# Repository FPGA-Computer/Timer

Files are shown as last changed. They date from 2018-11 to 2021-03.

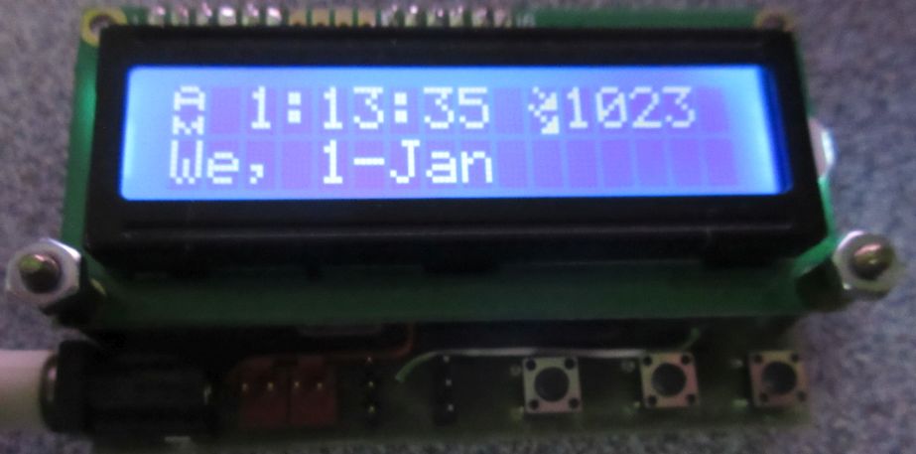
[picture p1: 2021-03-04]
V2/hardware/PCB + LCD.jpg

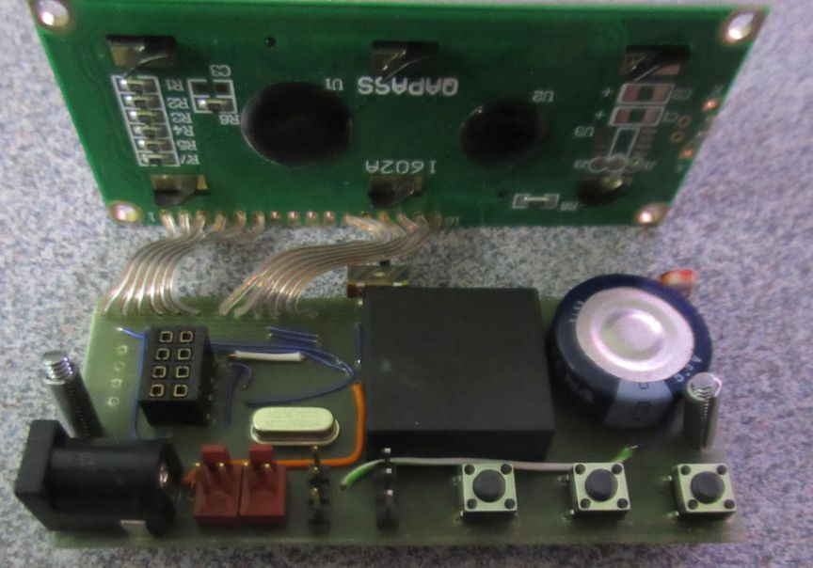
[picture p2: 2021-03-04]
V2/hardware/PCB top.jpg

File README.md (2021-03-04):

STM8S003 Timer

This is a timer for watering plant and supplyment light in the winter with LED.
There is a simple menu system (UI.C,UI.H) for setting preferences that may be of interest.

Schematic/layout: Eagle CAD. Firmware compiled using "Free" Cosmic C for the STM8 series.

Project page:

https://hw-by-design.blogspot.com/2018/10/stm8-timer.html

Licensing:

Firmware: Unless otherwise stated are in GPL3.0. stm8s.h is licensed under "MCD-ST Liberty SW License Agreement V2"

Schematic: Creative Commons 4.0 Attribution 4.0 International

PCB & Layout: Creative Commons 4.0 Attribution 4.0 International

See https://creativecommons.org/licenses/by/4.0/

Change log
- back port from LED clock project: NCO for better trimming, Daylight Saving Time, Date and leap year

- Mar 18 2020: Servo support + fixing alarm remainder time after time adjustment

- Mar 4 2021: V2 hardware/firmware release.  V1 will no longer be maintained

Hardware changes:

* Supercap backup power, switcher module

* Different connector for LED/sensor + Servo connector

* LCD, buttons I/O changes. LCD backlight on/off control by ambient light

* I2C connector

* expansion connector for nRF24 (no firmware support)

See https://hw-by-design.blogspot.com/2020/03/stm8-timer-servo-controlled-water-valve.html

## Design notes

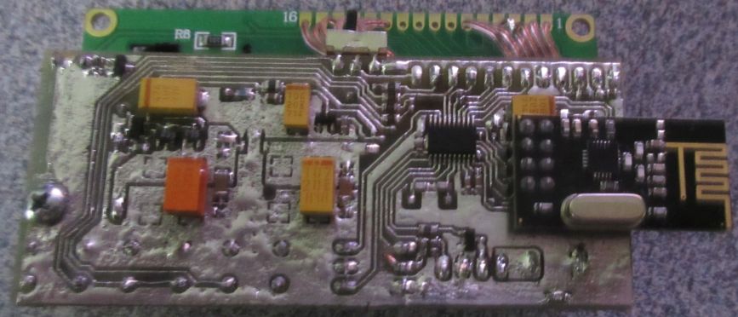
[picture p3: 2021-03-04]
V2/hardware/PCB with nRF24 module.jpg

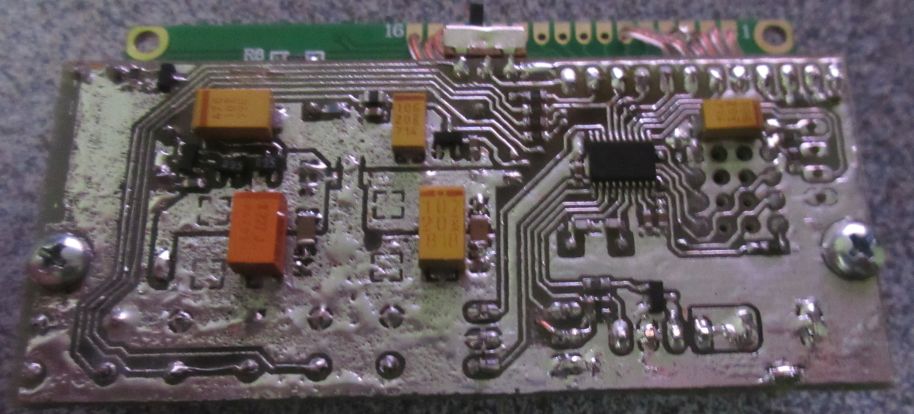
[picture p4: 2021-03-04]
V2/hardware/PCB bot.jpg

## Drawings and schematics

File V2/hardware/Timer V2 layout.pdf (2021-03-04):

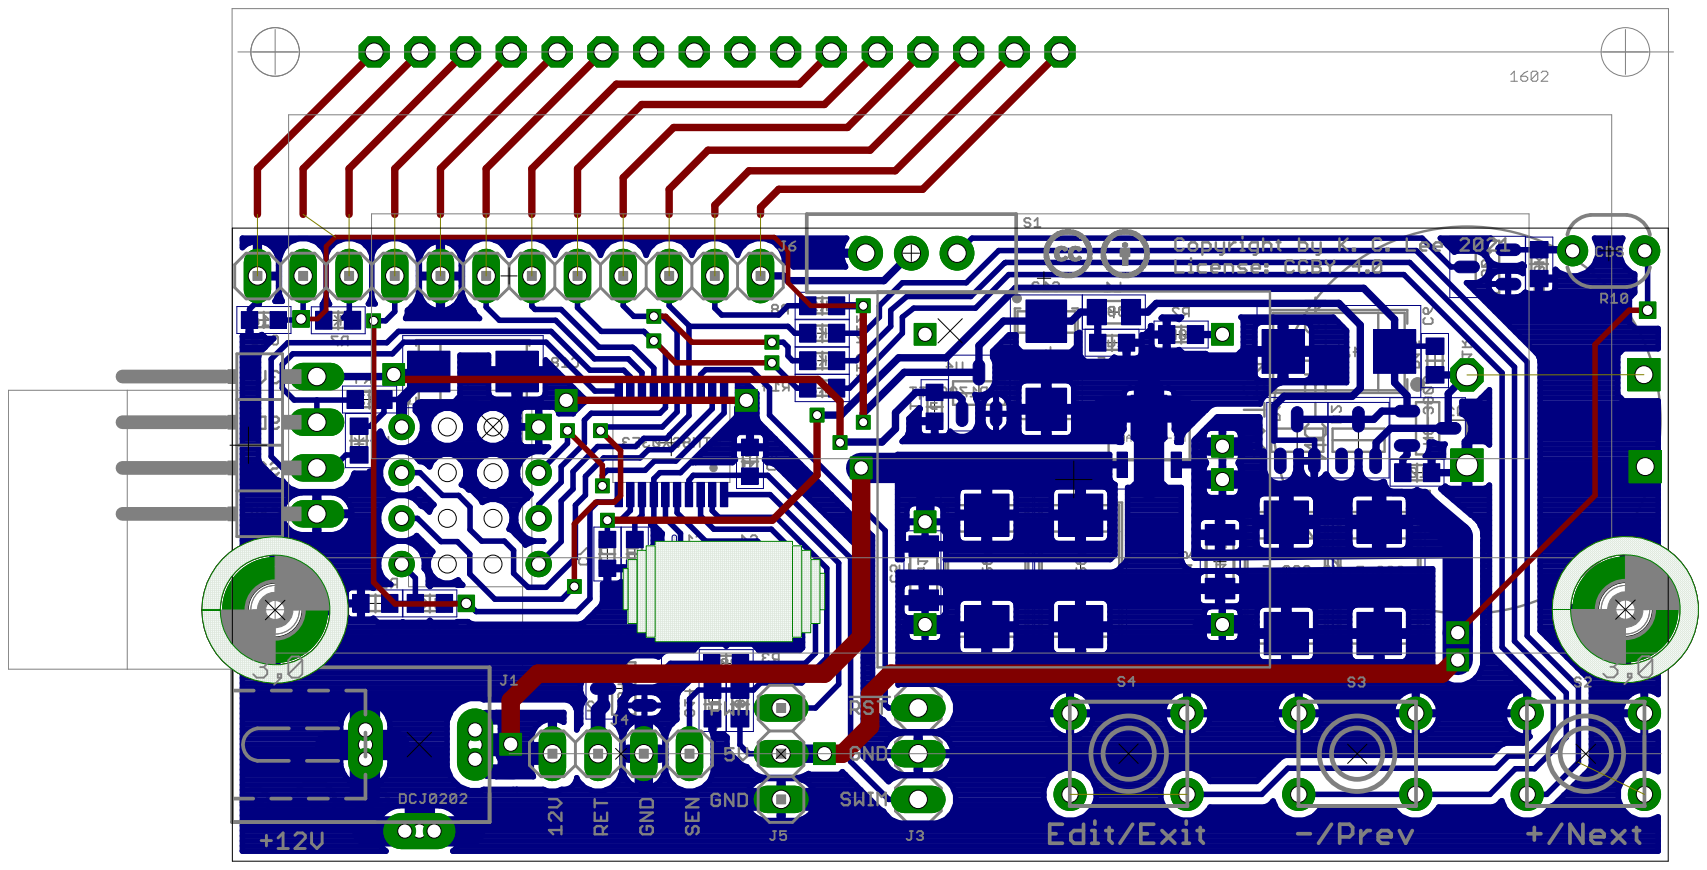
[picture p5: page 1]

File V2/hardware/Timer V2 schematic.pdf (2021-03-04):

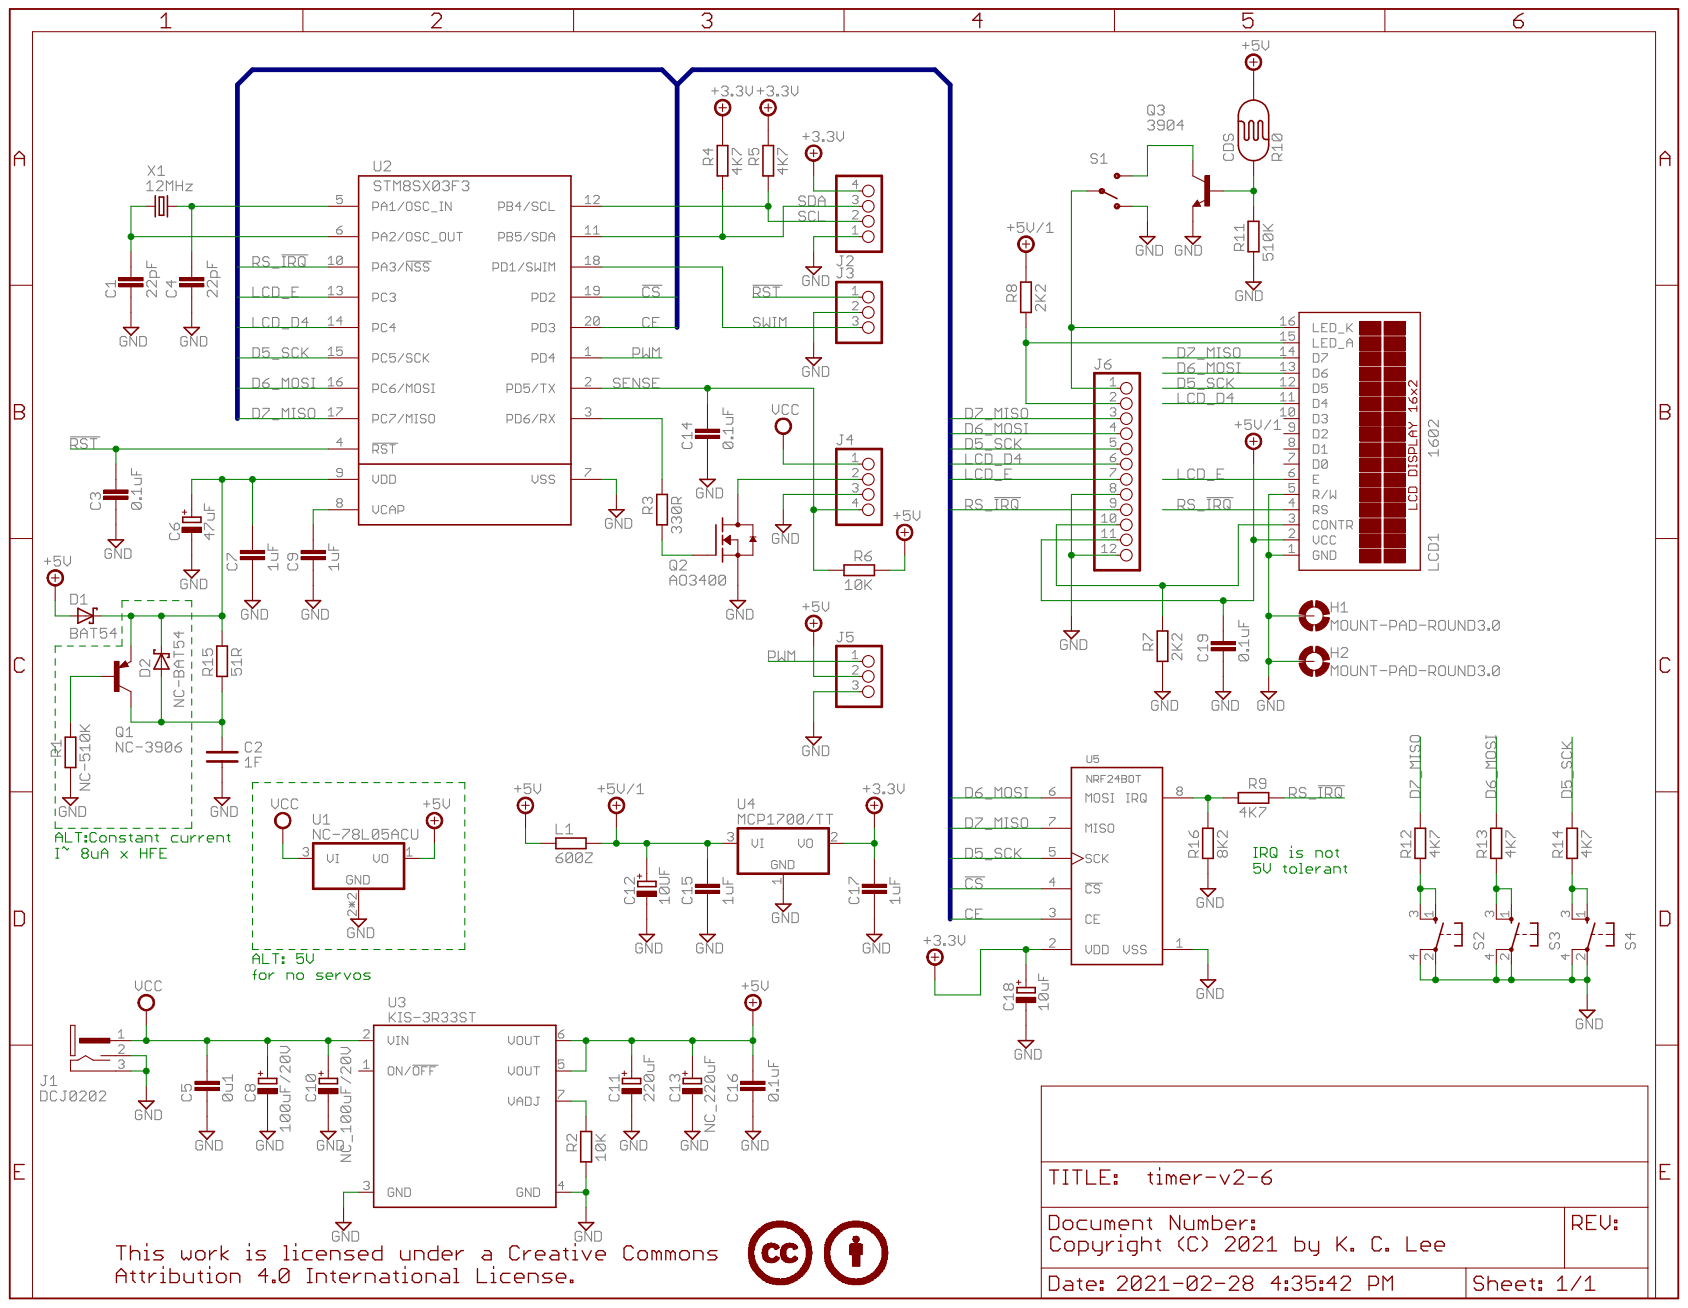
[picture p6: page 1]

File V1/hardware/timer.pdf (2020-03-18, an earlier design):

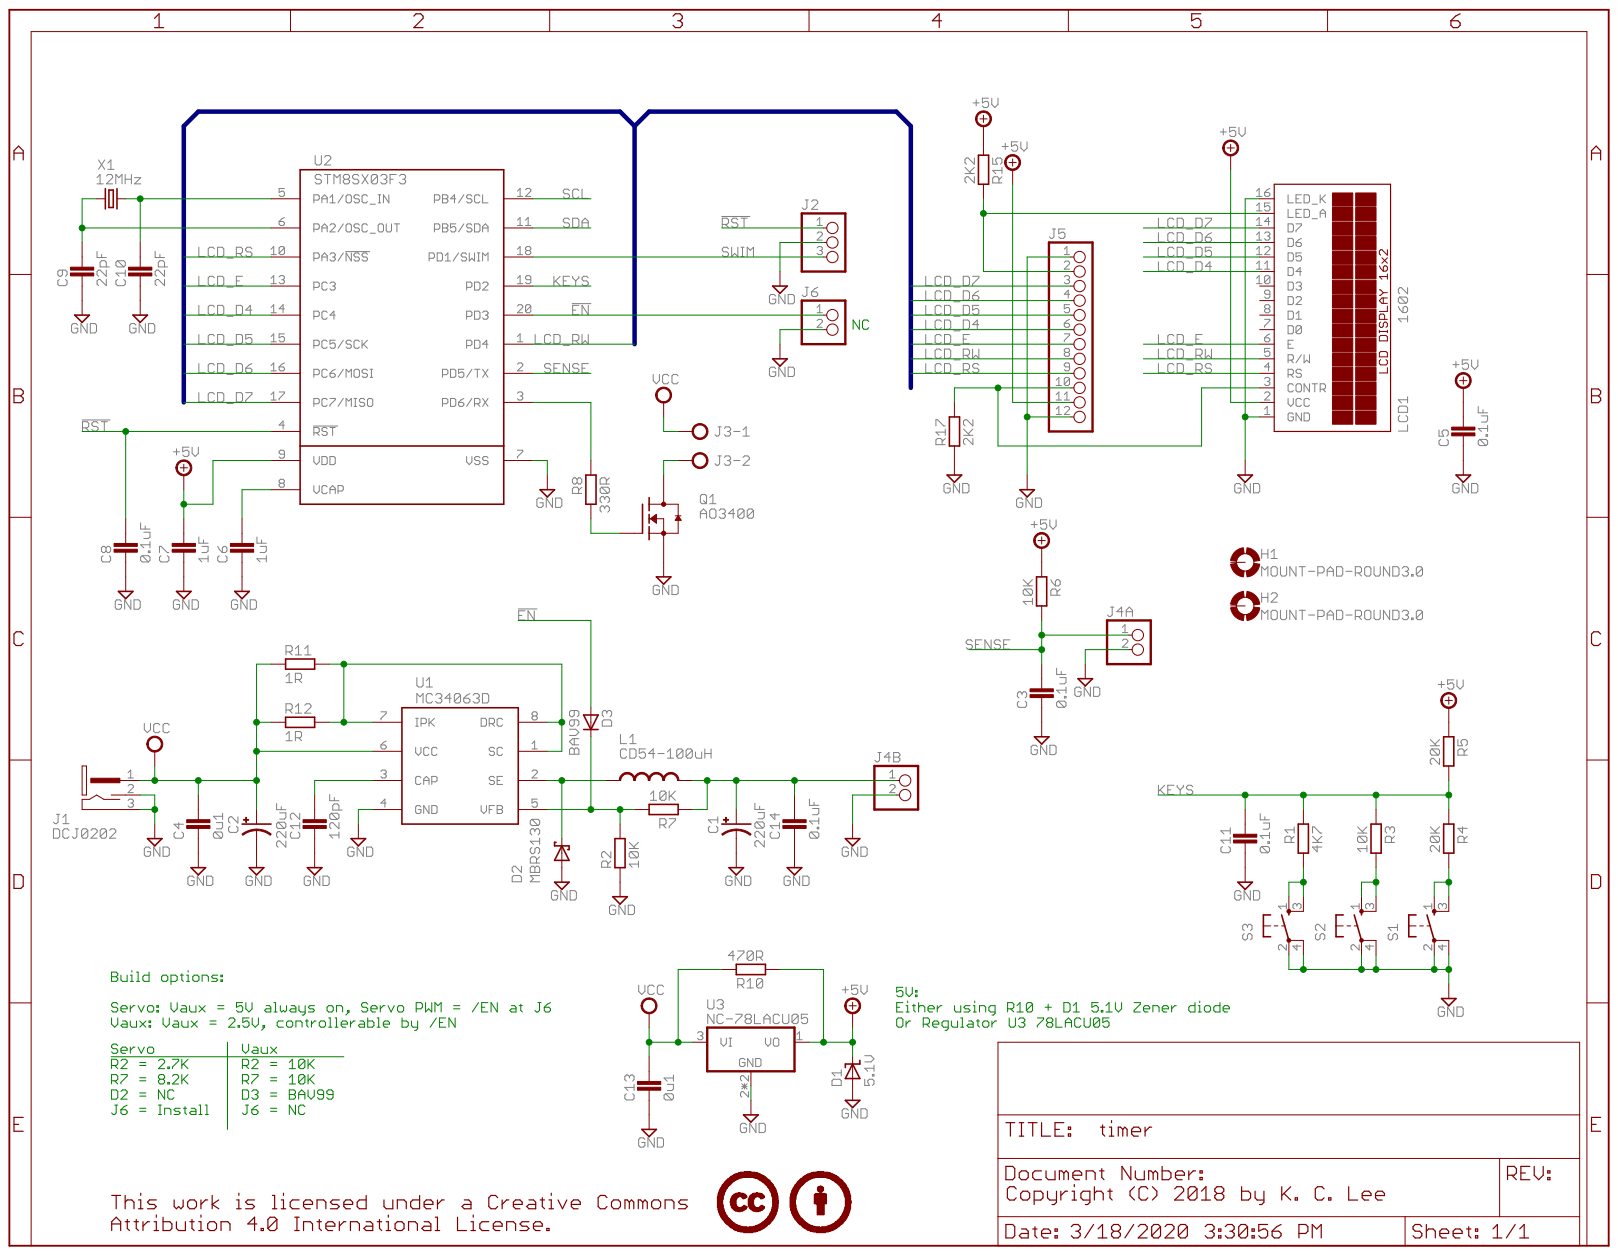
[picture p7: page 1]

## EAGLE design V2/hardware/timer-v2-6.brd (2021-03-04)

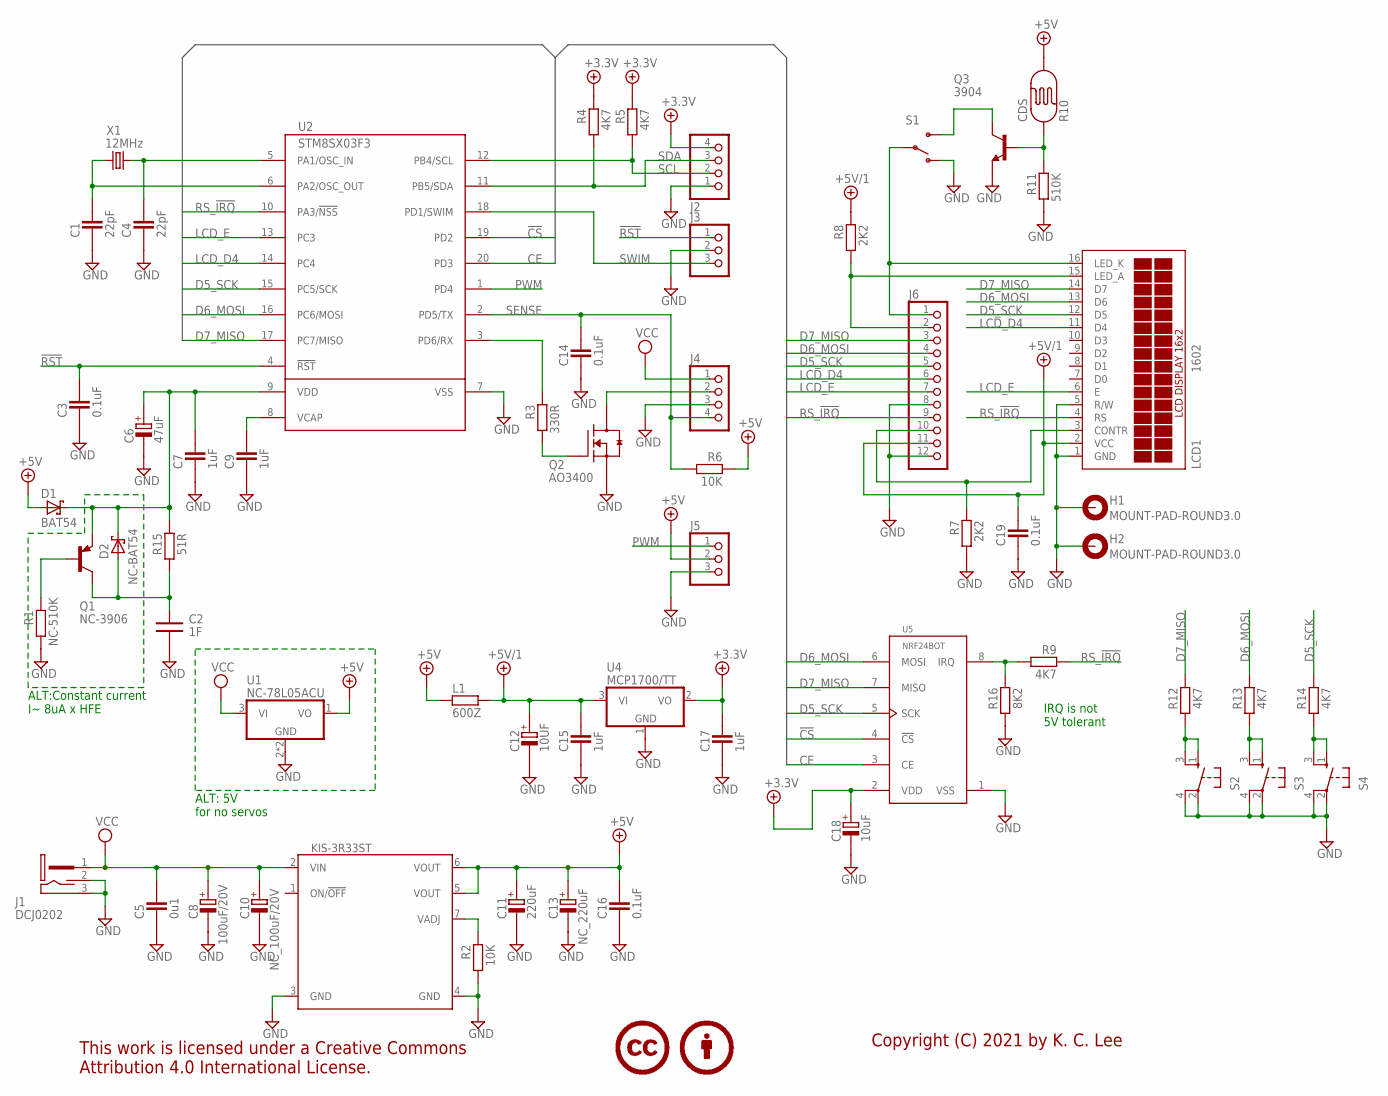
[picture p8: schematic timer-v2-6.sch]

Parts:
C1, C4: 22pF; CAPC1608X92N
C2: 1F; ELNA_DB_LOW
C3, C14, C19: 0.1uF; CAPC1608X92N
C5: 0u1; CAPC3215X168N
C6: 47uF; CAPMP7343X310N
C7, C9, C15, C17: 1uF; CAPC1608X92N
C8: 100uF/20V; CAPMP7343X430N
C10: NC_100uF/20V; CAPMP7343X430N
C11: 220uF; CAPMP7343X430N
C12: 10UF; CAPMP6032X280N
C13: NC_220uF; CAPMP7343X430N
C16: 0.1uF; CAPC3215X168N
C18: 10uF; CAPMP6032X280N
D1: BAT54; SOT95P280X135-3N
D2: NC-BAT54; SOT95P280X135-3N
H1, H2: MOUNT-PAD-ROUND3.0; 3,0-PAD
J1: DCJ0202; DCJ0202-SLOTTED
J2: PINHD-1X4_2.54-90°; 1X04/90
J3, J5: PINHD-1X3_2.54; 1X03
J4: PINHD-1X4_2.54; 1X04
J6: PINHD-1X12_2.54; 1X12
L1: 600Z; RESC2012X70N
LCD1: 1602; TUXGR_16X2_R2_NM
LICENSE1: CC-BY100%; CC-BY-100
Q1: NC-3906; SOT95P280X135-3N
Q2: AO3400; SOT95P280X135-3N
Q3: 3904; SOT95P280X135-3N
R1: NC-510K; RESC1608X55N
R2, R6: 10K; RESC1608X55N
R3: 330R; RESC1608X55N
R4, R5, R9, R12, R13, R14: 4K7; RESC1608X55N
R7, R8: 2K2; RESC1608X55N
R10: CDS; PHOTOCELL
R11: 510K; RESC1608X55N
R15: 51R; RESC1608X55N
R16: 8K2; RESC1608X55N
S1: SWITCH-SPDTPTH; SWITCH-SPDT
S2, S3, S4: MOM_SWTH; MOM_SW
U1: NC-78L05ACU; SOT89
U2: STM8SX03F3; TSSOP20
U3: KIS-3R33ST; KIS-3R33S-THRU
U4: MCP1700/TT; SOT95P280X135-3N
U5: NRF24BOT; NRF24L01-BOT
X1: 12MHz; HC49U-V

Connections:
!CS: U2.19 (PD2), U5.4 (!CS)
!RST: C3.2, J3.1, U2.4 (!RST)
+3.3V: C17.2, C18.+, J2.4, R4.1, R5.1, U4.2 (VO), U5.2 (VDD)
+5V: C11.+, C13.+, C16.2, D1.1 (A), J5.2, L1.1, R6.1, R10.2, U1.1 (VO), U3.5 (VOUT), U3.6 (VOUT)
+5V/1: C12.+, C15.2, C19.2, J6.11, L1.2, LCD1.2 (VCC), R8.1, U4.3 (VI)
CE: U2.20 (PD3), U5.3 (CE)
D5_SCK: J6.5, LCD1.12 (D5), R14.1, U2.15 (PC5/SCK), U5.5 (SCK)
D6_MOSI: J6.4, LCD1.13 (D6), R13.1, U2.16 (PC6/MOSI), U5.6 (MOSI)
D7_MISO: J6.3, LCD1.14 (D7), R12.1, U2.17 (PC7/MISO), U5.7 (MISO)
GND: C1.1, C2.-, C3.1, C4.1, C5.1, C6.-, C7.1, C8.-, C9.1, C10.-, C11.-, C12.-, C13.-, C14.1, C15.1, C16.1, C17.1, C18.-, C19.1, H1.B3,0, H2.B3,0, J1.2, J1.3, J2.1, J3.2, J4.3, J5.3, J6.8, J6.12, LCD1.1 (GND), LCD1.5 (R/W), Q2.2 (S), Q3.2 (E), R1.2, R2.2, R7.2, R11.2, R16.2, S1.1 (O), S2.2 (3), S2.4, S3.2 (3), S3.4, S4.2 (3), S4.4, U1.2 (GND), U1.4 (GND), U2.7 (VSS), U3.3 (GND), U3.4 (GND), U4.1 (GND), U5.1 (VSS)
LCD_A: J6.2, LCD1.15 (LED_A), R8.2
LCD_D4: J6.6, LCD1.11 (D4), U2.14 (PC4)
LCD_E: J6.7, LCD1.6 (E), U2.13 (PC3)
unnamed: J4.2, Q2.3 (D)
unnamed: C9.2, U2.8 (VCAP)
unnamed: R2.1, U3.7 (VADJ)
unnamed: C4.2, U2.5 (PA1/OSC_IN), X1.2
unnamed: C1.2, U2.6 (PA2/OSC_OUT), X1.1
unnamed: J6.1, LCD1.16 (LED_K), S1.2
unnamed: C6.+, C7.2, D1.3 (K), D2.3 (K), Q1.2 (E), R15.1, U2.9 (VDD)
unnamed: C2.+, D2.1 (A), Q1.3 (C), R15.2
unnamed: R14.2, S4.1, S4.3 (2)
unnamed: Q1.1 (B), R1.1
unnamed: Q3.1 (B), R10.1, R11.1
unnamed: Q2.1 (G), R3.2
unnamed: R3.1, U2.3 (PD6/RX)
unnamed: R13.2, S3.1, S3.3 (2)
unnamed: R12.2, S2.1, S2.3 (2)
unnamed: R9.2, R16.1, U5.8 (IRQ)
unnamed: Q3.3 (C), S1.3 (S)
unnamed: J6.10, LCD1.3 (CONTR), R7.1
PWM: J5.1, U2.1 (PD4)
RS_!IRQ: J6.9, LCD1.4 (RS), R9.1, U2.10 (PA3/!NSS)
SCL: J2.2, R5.2, U2.12 (PB4/SCL)
SDA: J2.3, R4.2, U2.11 (PB5/SDA)
SENSE: C14.2, J4.4, R6.2, U2.2 (PD5/TX)
SWIM: J3.3, U2.18 (PD1/SWIM)
VCC: C5.2, C8.+, C10.+, J1.1, J4.1, U1.3 (VI), U3.2 (VIN)

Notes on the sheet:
Copyright (C) 2021 by K. C. Lee
ALT: 5V for no servos
ALT:Constant current I~ 8uA x HFE
IRQ is not 5V tolerant

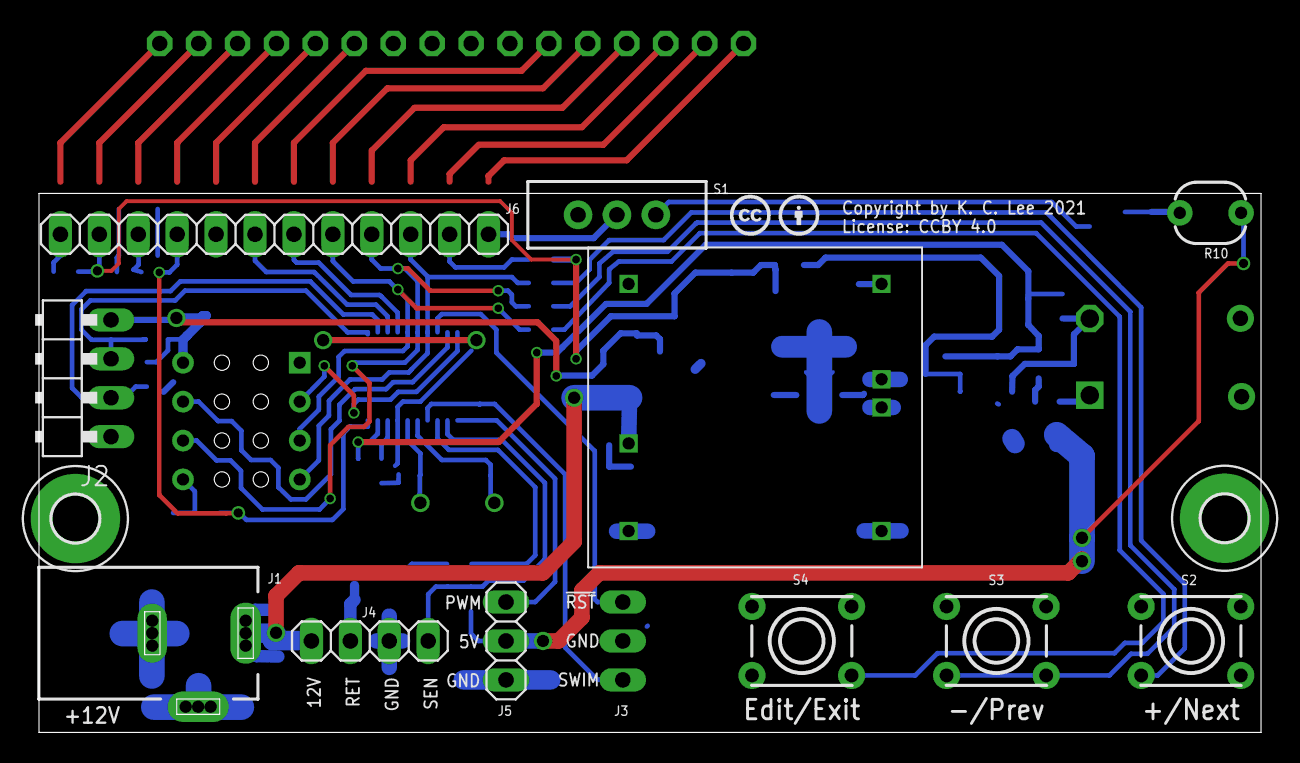
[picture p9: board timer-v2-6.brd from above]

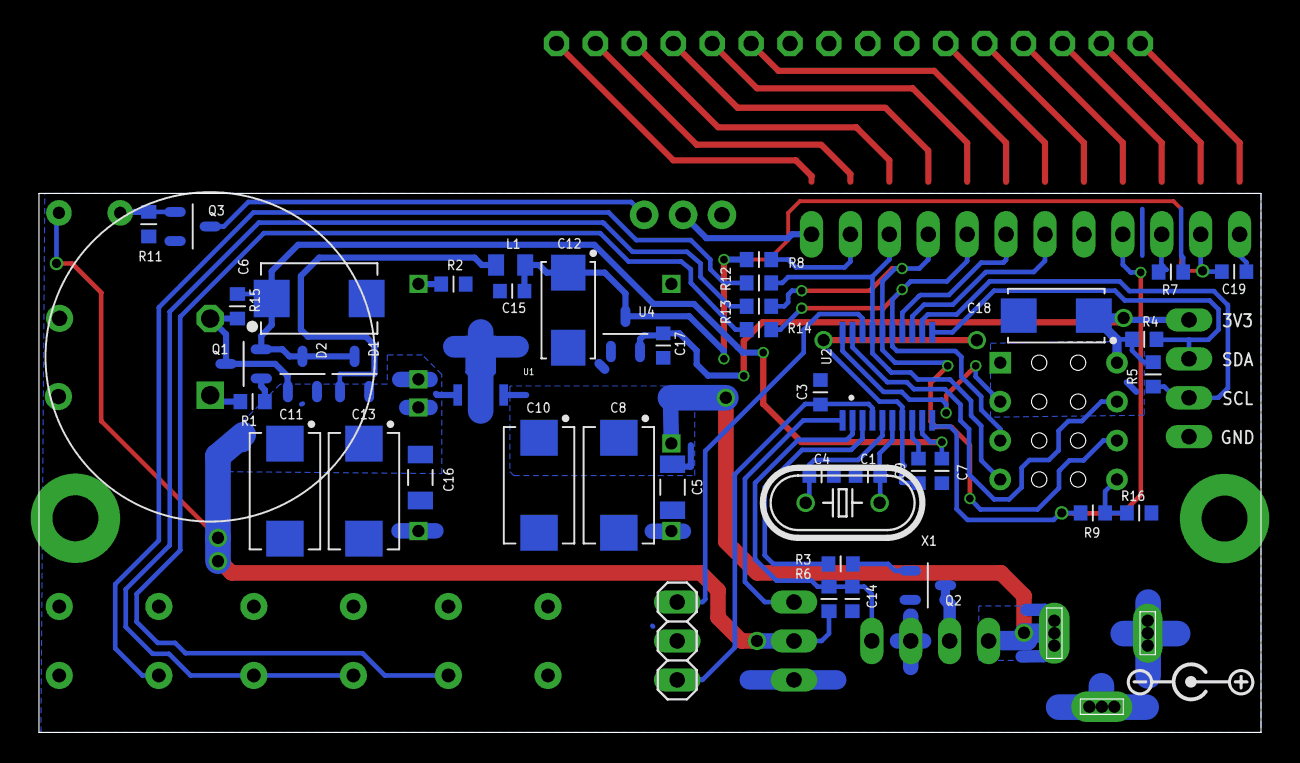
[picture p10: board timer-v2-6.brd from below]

Board: 2 copper layers, 79.8 x 35.2 mm, 62 parts (47 on the bottom side), 38 nets.

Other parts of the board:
U$1: POLARITY

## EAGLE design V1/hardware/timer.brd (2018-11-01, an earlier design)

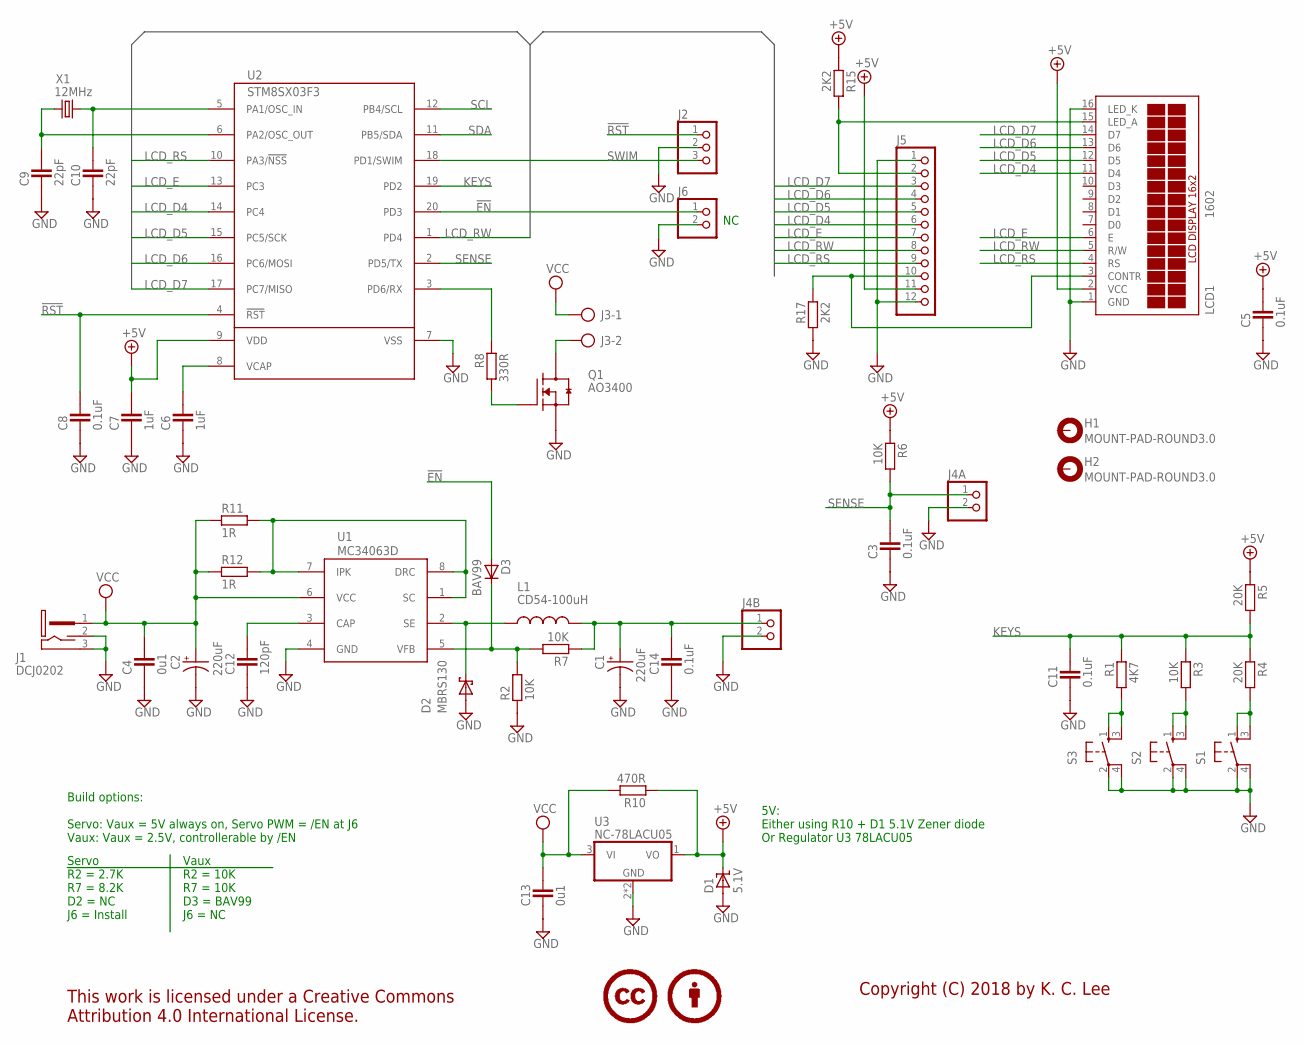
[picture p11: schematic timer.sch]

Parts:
C1, C2: 220uF; PANASONIC_G
C3, C5, C8, C11: 0.1uF; CAPC1608X92N
C4, C13: 0u1; CAPC2012X145AN
C6, C7: 1uF; CAPC1608X92N
C9, C10: 22pF; CAPC1608X92N
C12: 120pF; CAPC3215X168N
C14: 0.1uF; CAPC2012X145AN
D1: 5.1V; SOD2514X100N
D2: MBRS130; DIOM5436X265N
D3: BAV99; SOT95P280X135-3N
H1, H2: MOUNT-PAD-ROUND3.0; 3,0-PAD
J1: DCJ0202; DCJ0202-SLOTTED
J2: PINHD-1X3_2.54; 1X03
J3: AK500/2
J4A, J4B, J6: PINHD-1X2_2.54; 1X02
J5: PINHD-1X12_2.54; 1X12
L1: CD54-100uH; CD54
LCD1: 1602; TUXGR_16X2_R2_NM
LICENSE1: CC-BY100%; CC-BY-100
Q1: AO3400; SOT95P280X135-3N
R1: 4K7; RESC1608X55N
R2, R3, R6, R7: 10K; RESC1608X55N
R4, R5: 20K; RESC1608X55N
R8: 330R; RESC1608X55N
R10: 470R; RESC1608X55N
R11, R12: 1R; RESC2012X70N
R15, R17: 2K2; RESC1608X55N
S1, S2, S3: MOM_SWTH; MOM_SW
U1: MC34063D; SO-8
U2: STM8SX03F3; TSSOP20
U3: NC-78LACU05; SOT89
X1: 12MHz; SM49

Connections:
!EN: D3.1 (A), J6.1, U2.20 (PD3)
!RST: C8.2, J2.1, U2.4 (!RST)
+5V: C5.2, C7.2, D1.K, J5.11, LCD1.2 (VCC), R5.1, R6.1, R10.1, R15.1, U2.9 (VDD), U3.1 (VO)
+VOUT: C1.+, C14.2, J4B.1, L1.2, R7.1
GND: C1.-, C2.-, C3.1, C4.1, C5.1, C6.1, C7.1, C8.1, C9.1, C10.1, C11.1, C12.1, C13.1, C14.1, D1.A, D2.A, J1.2, J1.3, J2.2, J4A.2, J4B.2, J5.1, J5.12, J6.2, LCD1.1 (GND), LCD1.16 (LED_K), Q1.2 (S), R2.1, R17.2, S1.2 (3), S1.4, S2.2 (3), S2.4, S3.2 (3), S3.4, U1.4 (GND), U2.7 (VSS), U3.2 (GND), U3.4 (GND)
KEYS: C11.2, R1.1, R3.1, R4.1, R5.2, U2.19 (PD2)
LCD_A: J5.2, LCD1.15 (LED_A), R15.2
LCD_D4: J5.6, LCD1.11 (D4), U2.14 (PC4)
LCD_D5: J5.5, LCD1.12 (D5), U2.15 (PC5/SCK)
LCD_D6: J5.4, LCD1.13 (D6), U2.16 (PC6/MOSI)
LCD_D7: J5.3, LCD1.14 (D7), U2.17 (PC7/MISO)
LCD_E: J5.7, LCD1.6 (E), U2.13 (PC3)
LCD_RS: J5.9, LCD1.4 (RS), U2.10 (PA3/!NSS)
LCD_RW: J5.8, LCD1.5 (R/W), U2.1 (PD4)
unnamed: J3.2, Q1.3 (D)
unnamed: C6.2, U2.8 (VCAP)
unnamed: D3.3 (K), R2.2, R7.2, U1.5 (VFB)
unnamed: C10.2, U2.5 (PA1/OSC_IN), X1.2
unnamed: C9.2, U2.6 (PA2/OSC_OUT), X1.1
unnamed: R11.2, R12.2, U1.1 (SC), U1.7 (IPK), U1.8 (DRC)
unnamed: D2.K, L1.1, U1.2 (SE)
unnamed: C12.2, U1.3 (CAP)
unnamed: R4.2, S1.1, S1.3 (2)
unnamed: Q1.1 (G), R8.2
unnamed: R8.1, U2.3 (PD6/RX)
unnamed: R3.2, S2.1, S2.3 (2)
unnamed: R1.2, S3.1, S3.3 (2)
unnamed: J5.10, LCD1.3 (CONTR), R17.1
SCL: U2.12 (PB4/SCL)
SDA: U2.11 (PB5/SDA)
SENSE: C3.2, J4A.1, R6.2, U2.2 (PD5/TX)
SWIM: J2.3, U2.18 (PD1/SWIM)
VCC: C2.+, C4.2, C13.2, J1.1, J3.1, R10.2, R11.1, R12.1, U1.6 (VCC), U3.3 (VI)

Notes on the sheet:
Copyright (C) 2018 by K. C. Lee
Servo R2 = 2.7K R7 = 8.2K D2 = NC J6 = Install
Vaux R2 = 10K R7 = 10K D3 = BAV99 J6 = NC
Build options: Servo: Vaux = 5V always on, Servo PWM = /EN at J6 Vaux: Vaux = 2.5V, controllerable by /EN
5V: Either using R10 + D1 5.1V Zener diode Or Regulator U3 78LACU05

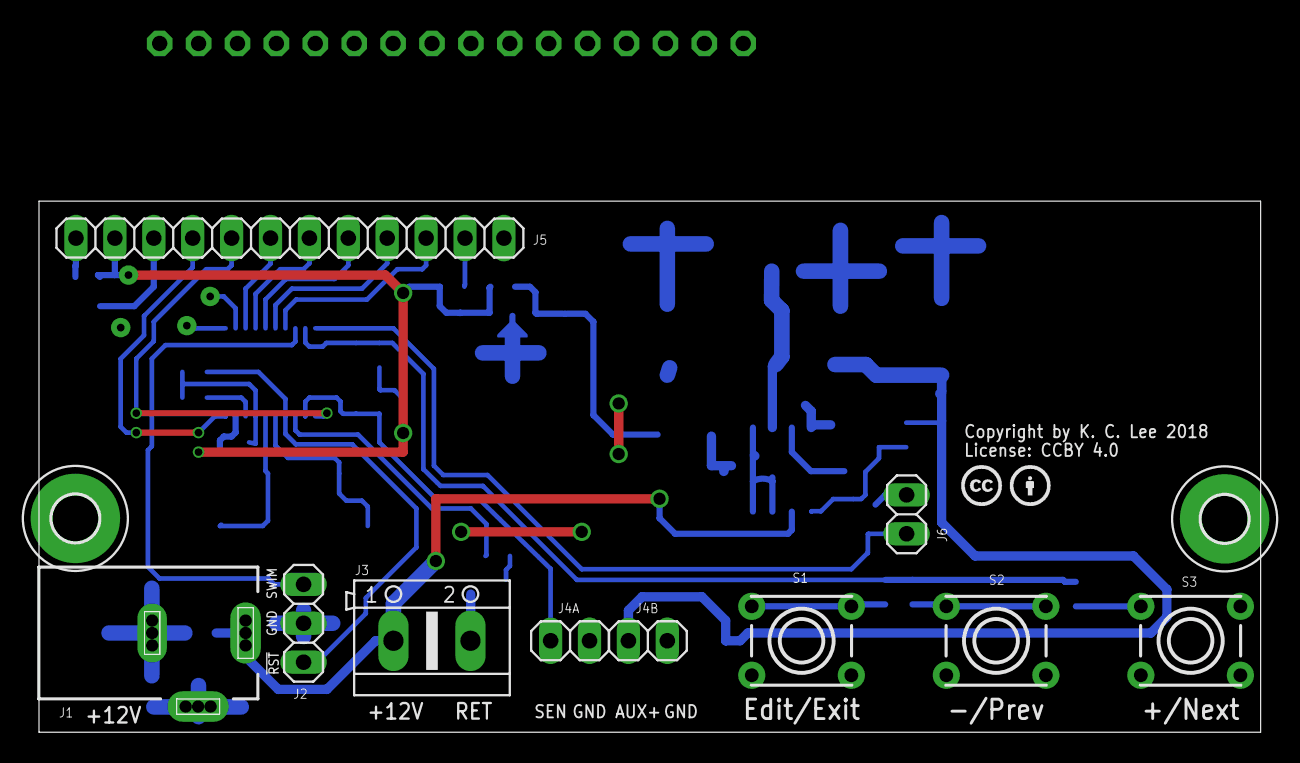
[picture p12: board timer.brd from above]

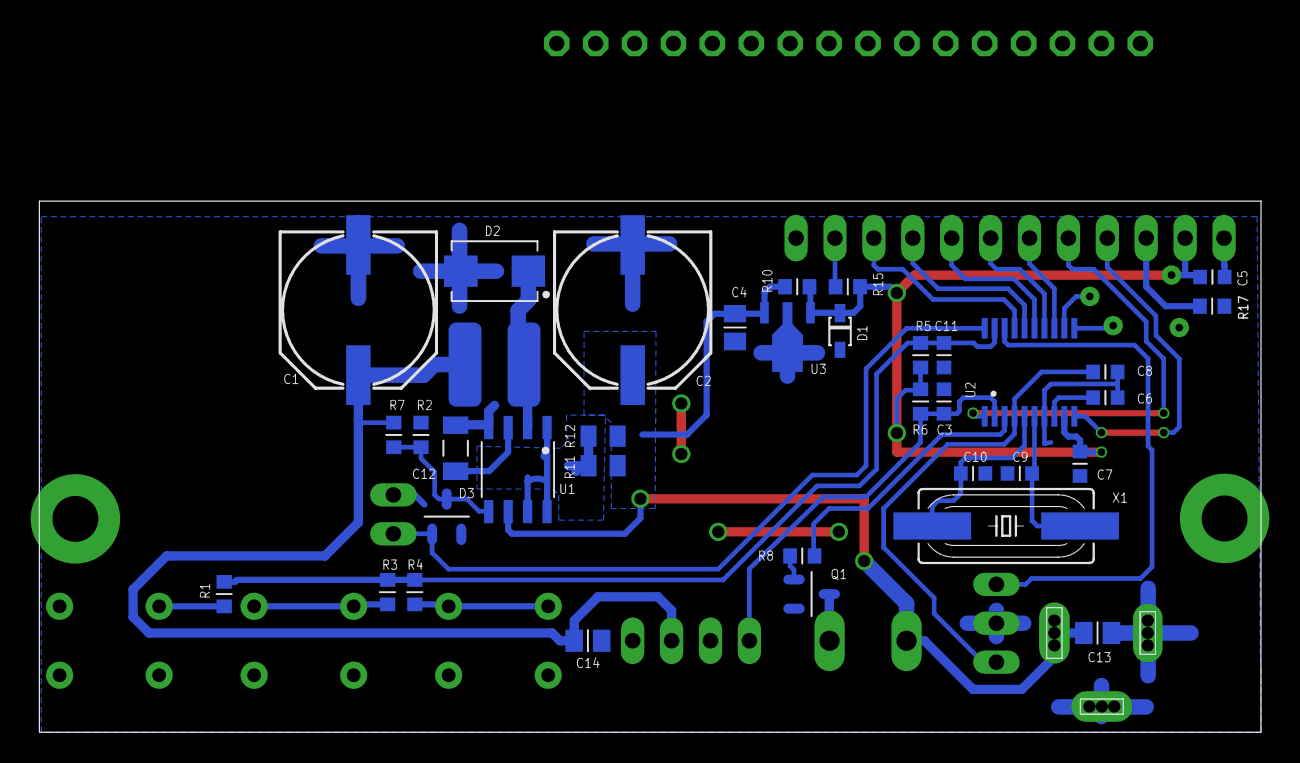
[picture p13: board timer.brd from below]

Board: 2 copper layers, 79.8 x 34.7 mm, 50 parts (36 on the bottom side), 31 nets.

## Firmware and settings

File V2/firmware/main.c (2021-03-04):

/*
 * main.c
 *
 * Created: October-19-18, 2:38:15 PM
 *  Author: K. C. Lee
 * Copyright (c) 2017 by K. C. Lee
 
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
 If not, see http://www.gnu.org/licenses/gpl-3.0.en.html 
 */
 
#include "hardware.h"
#include "main.h"

uint16_t ADC_Result;

void DisplayTask(void)
{
	LCD_Moveto(CLOCK_X,CLOCK_Y);
	Print_Time(&time,DISPLAY_SEC);
	LCD_Puts(" \x0b");
	Print_uint(ADC_Result,4,RightJustify);

  LCD_Moveto(STATUS_X,STATUS_Y);
	LCD_Puts((PERIPH_PORT->ODR & LED_EN)?"LED ":"    ");
	LCD_Puts(MOTOR_FLAG?"ON":"  ");
	
	LCD_Moveto(DATE_X,DATE_Y);
	Print_Date(&time,0);	
}

void main(void)
{	
	// load Alarm
	Load_Prefs(&Prefs);
	Init_Hardware();
	
	while(1)
	{	
		if(!debugger)
			wfi();	
	
		PowerDetect();
	
		if(power)
		{	
			switch(Key_Get())
			{
				case KEY_MENU|KEY_LONG:
					Setup();
					break;
			}
			
			if(time.SecFlag)
			{
				time.SecFlag = 0;
				ADC_Result = Read_ADC();
				DisplayTask();
			}
		}
	}
}

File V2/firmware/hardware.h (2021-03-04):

/*
 * hardware.h
 *
 * Created: October-19-18, 12:25:42 PM
 *  Author: K. C. Lee
 * Copyright (c) 2016 by K. C. Lee
 
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
 If not, see http://www.gnu.org/licenses/gpl-3.0.en.html 
 */ 

#ifndef HARDWARE_H_
#define HARDWARE_H_

#ifndef __CSMC__
#define __CSMC__
#endif
#define STM8S003

#include "stm8s.h"
#include <stdio.h>

// STM8S003F3P6
enum _PA { PA1=0x02, PA2=0x04, PA3=0x08 };
enum _PB { PB4=0x10, PB5=0x20 };
enum _PC { PC3=0x08, PC4=0x10, PC5=0x20, PC6=0x40, PC7=0x80 };
enum _PD { PD1=0x02, PD2=0x04, PD3=0x08, PD4=0x10, PD5=0x20, PD6=0x40 };

#include "irq.h"

#define CPU_CLOCK								12000000UL
#define EE_Addr									0x4000

#define LCD_E										PC3
#define LCD_DATA								(PC4|PC5|PC6|PC7)
#define LCD_RS									PA3
#define LCD_RS_PORT							GPIOA
#define LCD_E_PORT							GPIOC
#define LCD_DATA_PORT						GPIOC

#define KEY_PORT								LCD_DATA_PORT

#define I2C_SDA									PB5
#define I2C_SCK									PB4
#define I2C_PINS								(I2C_SDA|I2C_SCK)
#define I2C_PORT								GPIOB

// CPU divider = 1 -> 12MHz
//#define CPU_DIV					0

// CPU divider = 16 -> 750kHz
//#define CPU_DIV					0x04
// CPU divider = 4 -> 3MHz
#define CPU_DIV					0x00
// CPU divider = 128 -> 93.75kHz
#define CPU_SLOW				0x07							

enum _KEY_CODES
{	KEY_MENU=PC5, KEY_DEC=PC6, KEY_INC=PC7, KEY_MASK=(PC5|PC6|PC7) };

#define NRF_IRQ									LCD_RS
#define NRF_IRQ_PORT						LCD_RS_PORT

#define NRF_CE									PD2
#define NRF_CS									PD3
#define NRF_PORT								GPIOD

#define MOTOR_EN								PD4
#define LED_EN									PD6
#define PERIPH_PORT							GPIOD

#define LED_OFF()								PERIPH_PORT->ODR &= ~LED_EN
#define LED_ON()								PERIPH_PORT->ODR |= LED_EN

#define ADC_SENSE								5
#define ADC_MAX									1023
#define ADC_HYSTERESIS					5

#define DATA_KEY1								0xAE
#define DATA_KEY2								0x56

#define SERVO_FREQ							50
#define TIM2_DIV								4
#define TIM2_PSC								2			// 2^2
#define TIM2_RELOAD							(CPU_CLOCK/(TIM2_DIV*SERVO_FREQ))

// 12MHz/4 = 3MHz, resolution: 333ns
// Servo : 1.5ms + 0.5ms* X/90 
// Actual position determined empirically

#define SERVO_OFF								4600
#define SERVO_ON								1100

// wait 8 sec before shut down
#define SERVO_SHUTDOWN					(SERVO_FREQ*10)

extern uint8_t 	ServoFlag;
void Servo_Init(void);
void Servo_State(uint8_t State);
void Servo_Off(void);

#define MOTOR_OFF()							Servo_State(0)
#define MOTOR_ON()							Servo_State(1)
#define MOTOR_FLAG							ServoFlag

#define DELAY_ADJ(X)						(X*0.79)

#include "adc.h"
#include "LCD.h"
#include "time.h"
#include "key.h"
#include "ui.h"
#include "eeprom.h"
#include "menu.h"

void Init_Hardware(void);
void Delay(uint16_t Delay);
void PowerDetect(void);

extern uint16_t ADC_Result;
extern uint8_t power, debugger;
#endif

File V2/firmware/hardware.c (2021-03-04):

/*
 * hardware.c
 *
 * Created: October-19-18, 12:25:42 PM
 *  Author: K. C. Lee
 * Copyright (c) 2017 by K. C. Lee
 
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
 If not, see http://www.gnu.org/licenses/gpl-3.0.en.html 
 */ 

#include "hardware.h"

uint8_t power=1, debugger;

void Init_Hardware(void)
{
	// Switch clock enable
	CLK->SWCR |= CLK_SWCR_SWEN;
	// Select HSE
	CLK->SWR = 0xb4;
	// wait for switching
	while(CLK->SWCR & CLK_SWCR_SWBSY)
	  /* */ ;
	
	// Clk divider, CPU divider = 1
	CLK->CKDIVR = 0;
	debugger = RST->SR & RST_SR_SWIMF;
	
	// GPIO for outputs
	MOTOR_OFF();
	LED_OFF();
	
	PERIPH_PORT->DDR |= MOTOR_EN|LED_EN;
	PERIPH_PORT->CR1 |= MOTOR_EN|LED_EN;
	
	// Wait for power to be stabilized
	Delay(100);
	
	// Init peripherals
	LCD_Init();
	ADC_Init();
	Time_Init();
	Servo_Init();

	FLASH->DUKR = DATA_KEY1;
	FLASH->DUKR = DATA_KEY2;
	
	// Turn on interrupts
	rim();
}

void PowerDetect(void)
{
	uint8_t detect;

	// LCD data is internally pulled up to +5V
	detect=(LCD_DATA_PORT->IDR & LCD_DATA)!=0;

	if(power!=detect)		// power status change
	{
		if(detect)				// power returns
		{
			CLK->CKDIVR = CPU_DIV;
			// power up all peripherals
			CLK->PCKENR1 = CLK_PCKENR1_RESET_VALUE;
			CLK->PCKENR2 = CLK_PCKENR2_RESET_VALUE;
			// Wait for power to be stabilized
			Delay(1000);			
			LCD_Init();
			Servo_Init();			
		}
		else							// power outage
		{
			LCD_Off();
			Servo_Off();
			
			CLK->CKDIVR = CPU_SLOW;
			// power down all peripherals except TIM1 needed for RTC
			CLK->PCKENR1 = CLK_PCKENR1_TIM1;
			CLK->PCKENR2 = 0;
		}
		power = detect;
	}
}

// use DELAY_ADJ() for rough value in us

void Delay(uint16_t Delay)
{	
	for(;Delay;Delay--)
	{
		_asm("nop");
		_asm("nop");
		_asm("nop");
		_asm("nop");
	}
}

uint8_t Servo_CountDown, ServoFlag;

@far @interrupt void TIM2_IRQ(void)
{
	TIM2->SR1 = ~TIM2_SR1_UIF;								// Clear update IRQ
	
	if (Servo_CountDown >1)
		Servo_CountDown--;
	else if	(Servo_CountDown)
	{
		Servo_CountDown = 0;
		// turn off TIM2
		TIM2->CR1 = 0;	
	}
}

void Servo_State(uint8_t State)
{
	ServoFlag = State;
	TIM2->CR1 = TIM2_CR1_CEN;
	
	if(State)
	{
		TIM2->CCR1H = SERVO_ON >>8;
		TIM2->CCR1L = SERVO_ON & 0xff;
	}
	else
	{
		TIM2->CCR1H = SERVO_OFF >>8;
		TIM2->CCR1L = SERVO_OFF & 0xff;	
	}

	Servo_CountDown = SERVO_SHUTDOWN;
}

void Servo_Init(void)
{
	TIM2->PSCR = TIM2_PSC;
	TIM2->ARRH = (TIM2_RELOAD-1) >> 8;
	TIM2->ARRL = (TIM2_RELOAD-1) & 0xff;
	
	// Update interrupt
	TIM2->IER = TIM2_IER_UIE;
	
	// -- Servo -----
	// Ch2: PWM mode 1, preload enable
	TIM2->CCMR1 = (0x06 <<4)|TIM2_CCMR_OCxPE;
	// Capture pin output enable
	TIM2->CCER1 |= TIM2_CCER1_CC1E;

	Servo_State(0);
}

void Servo_Off(void)
{
	TIM2->CCER1 &= ~TIM2_CCER1_CC1E;
	TIM2->CR1 = 0;
	TIM2->IER = 0;
}

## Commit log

2018-11-01 re-release - update+fix licensing
    [timer.brd, timer.sch]
2018-11-21 Fix clock trim polarity
    [menu.c]
2020-01-26 Bug fix: Day of week, key repeat rate
    [hardware.h, time.c]
2020-03-18 Servo support + alarm remainder time
    [timer.sch]
2020-11-01 fix daylight saving time
    [time.c]
2021-03-04 add V2 hardware+firmware
    [timer-v2-6.brd, timer-v2-6.sch, timer.brd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]
2021-03-09 fix DST start/end dates
    [time.c]

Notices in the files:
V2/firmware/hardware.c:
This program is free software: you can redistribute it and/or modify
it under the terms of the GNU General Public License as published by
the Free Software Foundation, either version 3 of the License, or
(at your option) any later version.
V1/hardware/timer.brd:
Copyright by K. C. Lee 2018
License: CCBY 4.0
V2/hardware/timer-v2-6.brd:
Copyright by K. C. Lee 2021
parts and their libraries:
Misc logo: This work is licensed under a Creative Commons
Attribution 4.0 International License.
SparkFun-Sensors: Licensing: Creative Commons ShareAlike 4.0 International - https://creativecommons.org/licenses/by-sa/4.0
